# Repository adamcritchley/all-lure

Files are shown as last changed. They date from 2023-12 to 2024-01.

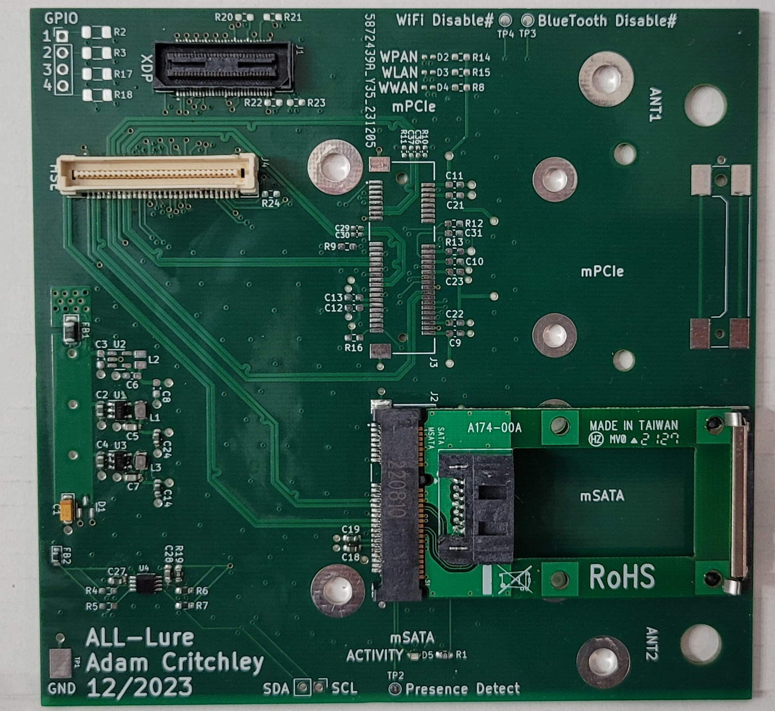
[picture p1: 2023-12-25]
images/top_with_sata.jpg

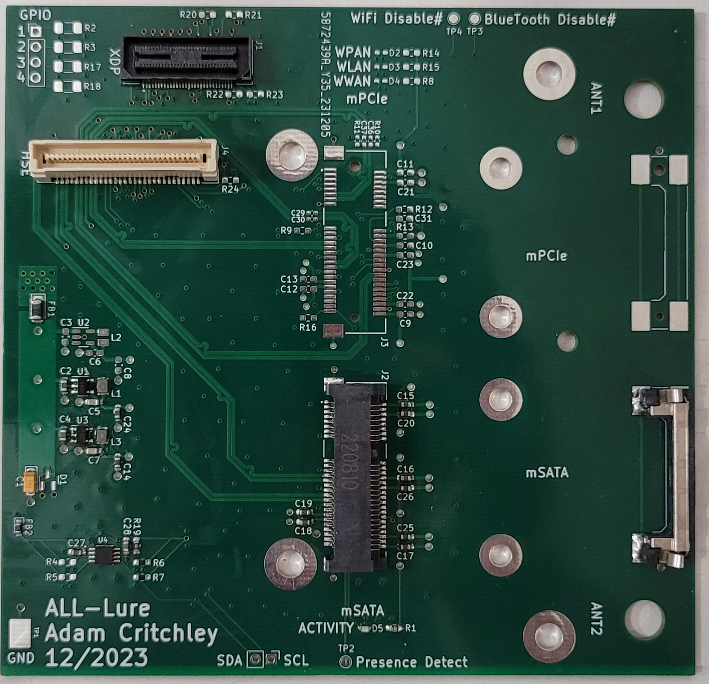
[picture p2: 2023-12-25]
images/top.jpg

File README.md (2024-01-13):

# Disclaimer
This board is still a prototype and is not functional. I was not able to fabricate it with working mSATA or mPCIe. I attempted to fabricate it with JLCPCB using both JLC041611-7628 and JLC041611-3313 impedance control. The presence detect for mSATA was pulled low however the MinnowBoard would not communicate with the mSATA card. I've decided not to continue troubleshooting this board and instead leave it as a learning experience in high-speed board design.

See [CM4-NAS-MiniPCIE](https://github.com/dumtux/CM4-NAS-MiniPCIE) as an example high-speed board designed for JLCPCB's JLC041611-7628 impedance control

# All-lure (GPIO, XDP, mPCIe, mSATA expansion for MinnowBoard)
All-lure is a custom "lure" expansion board for MinnowBoard Single Board Computers (SBC). The official hardware designs for MinnowBoard and the lures can be found at [MinnowBoards official GitHub](https://github.com/MinnowBoard-org/design-files). However, each board only exposes a single capability through the HSE (i.e. mSATA or mPCIe), instead I wanted a single board that combined as much of the lures capabilities into a single lure.

# Fabrication
This board does not work, please do not fabricate it. Currently it's designed for fabrication with JLCPCB using 1oz inner and outer copper weight and the standard JLC041611-7628 impedance control.

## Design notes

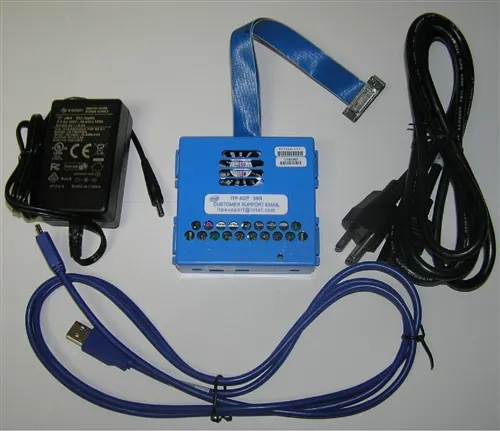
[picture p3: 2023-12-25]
images/ITPXDP3BREXT-2.png

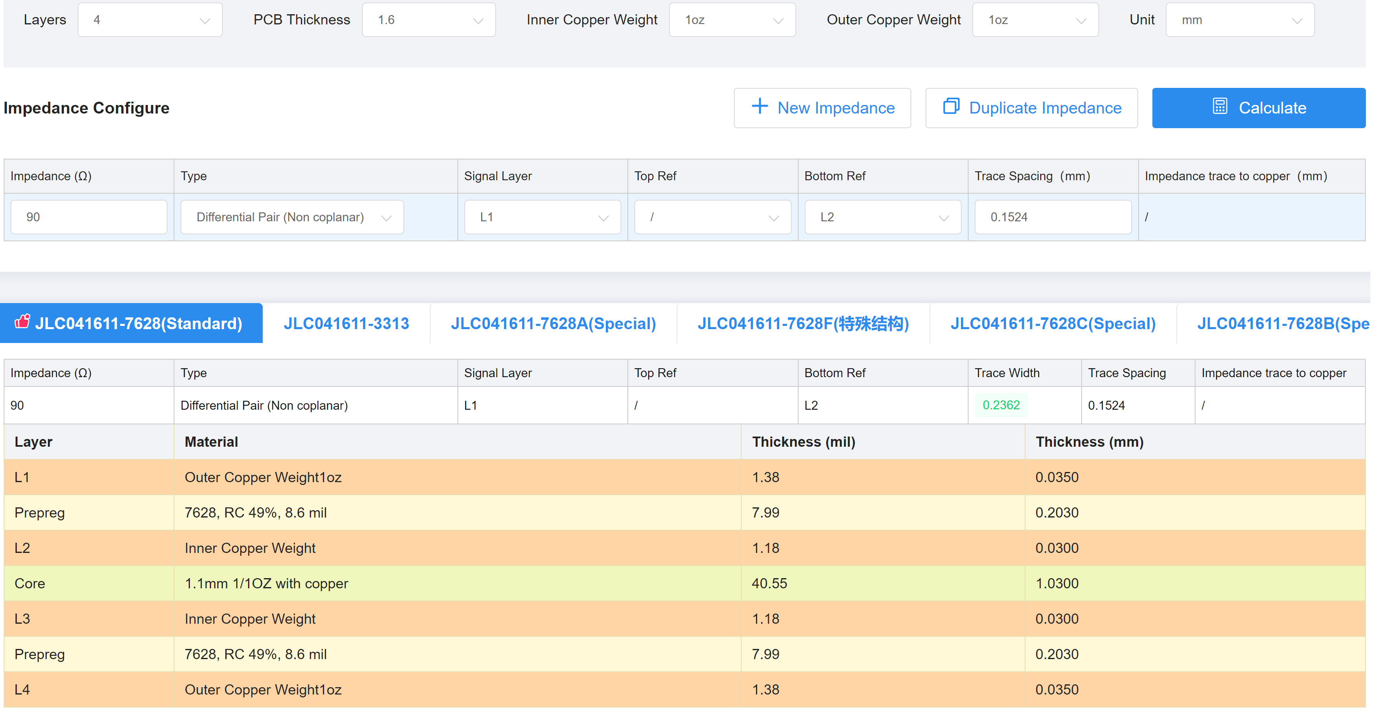
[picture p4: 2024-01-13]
images/usb_90R.png

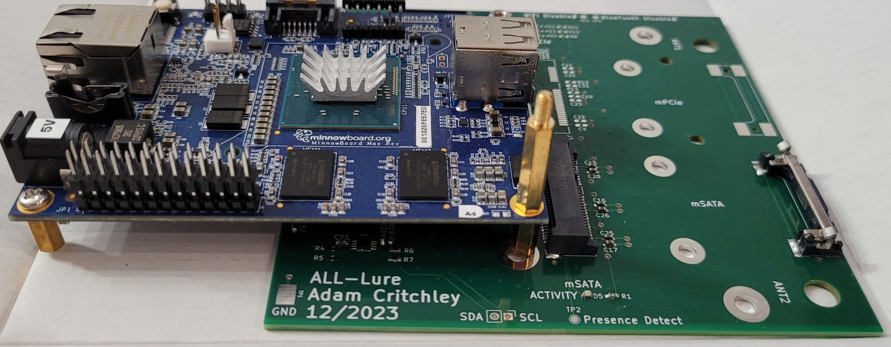
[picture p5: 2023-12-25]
images/side_mounted.jpg

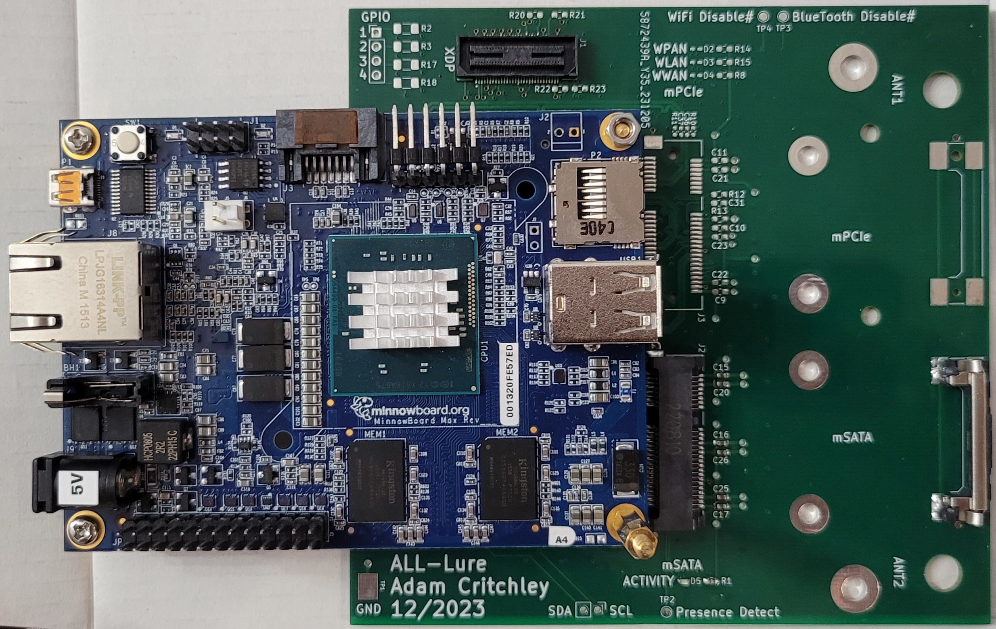
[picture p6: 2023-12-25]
images/top_mounted.jpg

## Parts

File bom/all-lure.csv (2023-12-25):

Index | Quantity | Part Number | Manufacturer Part Number | Description | Customer Reference | Available | Backorder | Unit Price | Extended Price USD
1 | 1 | 36-5095CT-ND | 5095 | SM TEST POINT ON T&R - COMPACT |  | 1 | 0 | 0.35000 | 0.35
2 | 1 | A99215CT-ND | 3-5177986-2 | CONN PLUG 60POS SMD GOLD |  | 1 | 0 | 4.06000 | 4.06
3 | 1 | SAM13103CT-ND | BSH-030-01-L-D-A-TR | CONN SOCKET 60POS SMD GOLD |  | 1 | 0 | 8.07000 | 8.07
4 | 2 | WM7125CT-ND | 0679105700 | CONN PCI EXP MIN FML 52POS 0.031 |  | 2 | 0 | 5.38000 | 10.76
5 | 2 | WM3733CT-ND | 0480995701 | LATCH ASSY FOR MINIPCI W/COVER |  | 2 | 0 | 1.70000 | 3.40
6 | 1 | 478-9042-1-ND | TPSA336K010R0700 | CAP TANT 33UF 10% 10V 1206 |  | 1 | 0 | 0.84000 | 0.84
7 | 4 | 160-1183-1-ND | LTST-C190GKT | LED GREEN CLEAR CHIP SMD |  | 4 | 0 | 0.23000 | 0.92
8 | 1 | 296-18509-1-ND | PCA9306DCTR | IC TRANSLATOR BIDIRECTIONAL SM8 |  | 1 | 0 | 0.65000 | 0.65
9 | 1 | 445-MMZ1608B601CTAH0CT-ND | MMZ1608B601CTAH0 | FERRITE BEAD 600 OHM 0603 1LN |  | 1 | 0 | 0.10000 | 0.10
10 | 3 | 587-5925-1-ND | MAKK2016T1R0M | FIXED IND 1UH 2.2A 75 MOHM SMD |  | 3 | 0 | 0.20000 | 0.60
11 | 1 | 587-LCMGA321616T221NGCT-ND | LCMGA321616T221NG | FERRITE BEAD 220 OHM 1206 1LN |  | 1 | 0 | 0.38000 | 0.38
12 | 3 | 1276-1274-1-ND | CL10A226MP8NUNE | CAP CER 22UF 10V X5R 0603 |  | 3 | 0 | 0.18000 | 0.54
13 | 2 | SC189ZSKCT-ND | SC189ZSKTRT | IC REG BUCK 3.3V 1.5A SOT23-5 |  | 2 | 0 | 1.20000 | 2.40
14 | 1 | 600-SC189HSKTRTCT-ND | SC189HSKTRT | IC REG BUCK 1.5V 1.5A SOT23-5 |  | 0 | 1 | 1.17000 | 1.17
15 | 1 | BAT54CLT3GOSCT-ND | BAT54CLT3G | DIODE ARR SCHOTT 30V 200MA SOT23 |  | 1 | 0 | 0.12000 | 0.12
16 | 3 | 1276-1019-1-ND | CL10B105KO8NNNC | CAP CER 1UF 16V X7R 0603 |  | 3 | 0 | 0.10000 | 0.30
17 | 18 | 1276-1005-1-ND | CL10B104KO8NNNC | CAP CER 0.1UF 16V X7R 0603 |  | 18 | 0 | 0.02600 | 0.47
18 | 4 | 4988-NMC0402X7R104K25TRPFCT-ND | NMC0402X7R104K25TRPF | CAP SMT04020.1F25VDC |  | 4 | 0 | 0.13000 | 0.52
19 | 3 | YAG5835CT-ND | SR0603FR-7T330RL | RES 330 OHM 1% 1/4W 0603 |  | 3 | 0 | 0.88000 | 2.64
20 | 3 | YAG5823CT-ND | SR0603FR-7T10KL | RES 10K OHM 1% 1/4W 0603 |  | 3 | 0 | 0.88000 | 2.64
21 | 2 | YAG5834CT-ND | SR0603FR-7T2K2L | RES 2.2K OHM 1% 1/4W 0603 |  | 2 | 0 | 0.88000 | 1.76
22 | 2 | YAG5821CT-ND | SR0603FR-7T100KL | RES 100K OHM 1% 1/4W 0603 |  | 2 | 0 | 0.88000 | 1.76
23 | 2 | 311-49.9LRCT-ND | RC0402FR-0749R9L | RES 49.9 OHM 1% 1/16W 0402 |  | 2 | 0 | 0.10000 | 0.20
24 | 1 | 13-RC0603FR-13200KLCT-ND | RC0603FR-13200KL | RES 200K OHM 1% 1/10W 0603 |  | 1 | 0 | 0.10000 | 0.10
25 | 3 | 13-RC0603JR-131KLCT-ND | RC0603JR-131KL | RES 1K OHM 5% 1/10W 0603 |  | 3 | 0 | 0.10000 | 0.30
26 | 4 | 311-10.0KFRCT-ND | RC1206FR-0710KL | RES 10K OHM 1% 1/4W 1206 |  | 4 | 0 | 0.10000 | 0.40
27 | 3 | 1276-1038-1-ND | CL10A106KQ8NNNC | CAP CER 10UF 6.3V X5R 0603 |  | 3 | 0 | 0.13000 | 0.39
28 | 4 | 952-2310-ND | R30-1000802 | HEX STANDOFF M3X0.5 BRASS 8MM |  | 4 | 0 | 0.58000 | 2.32

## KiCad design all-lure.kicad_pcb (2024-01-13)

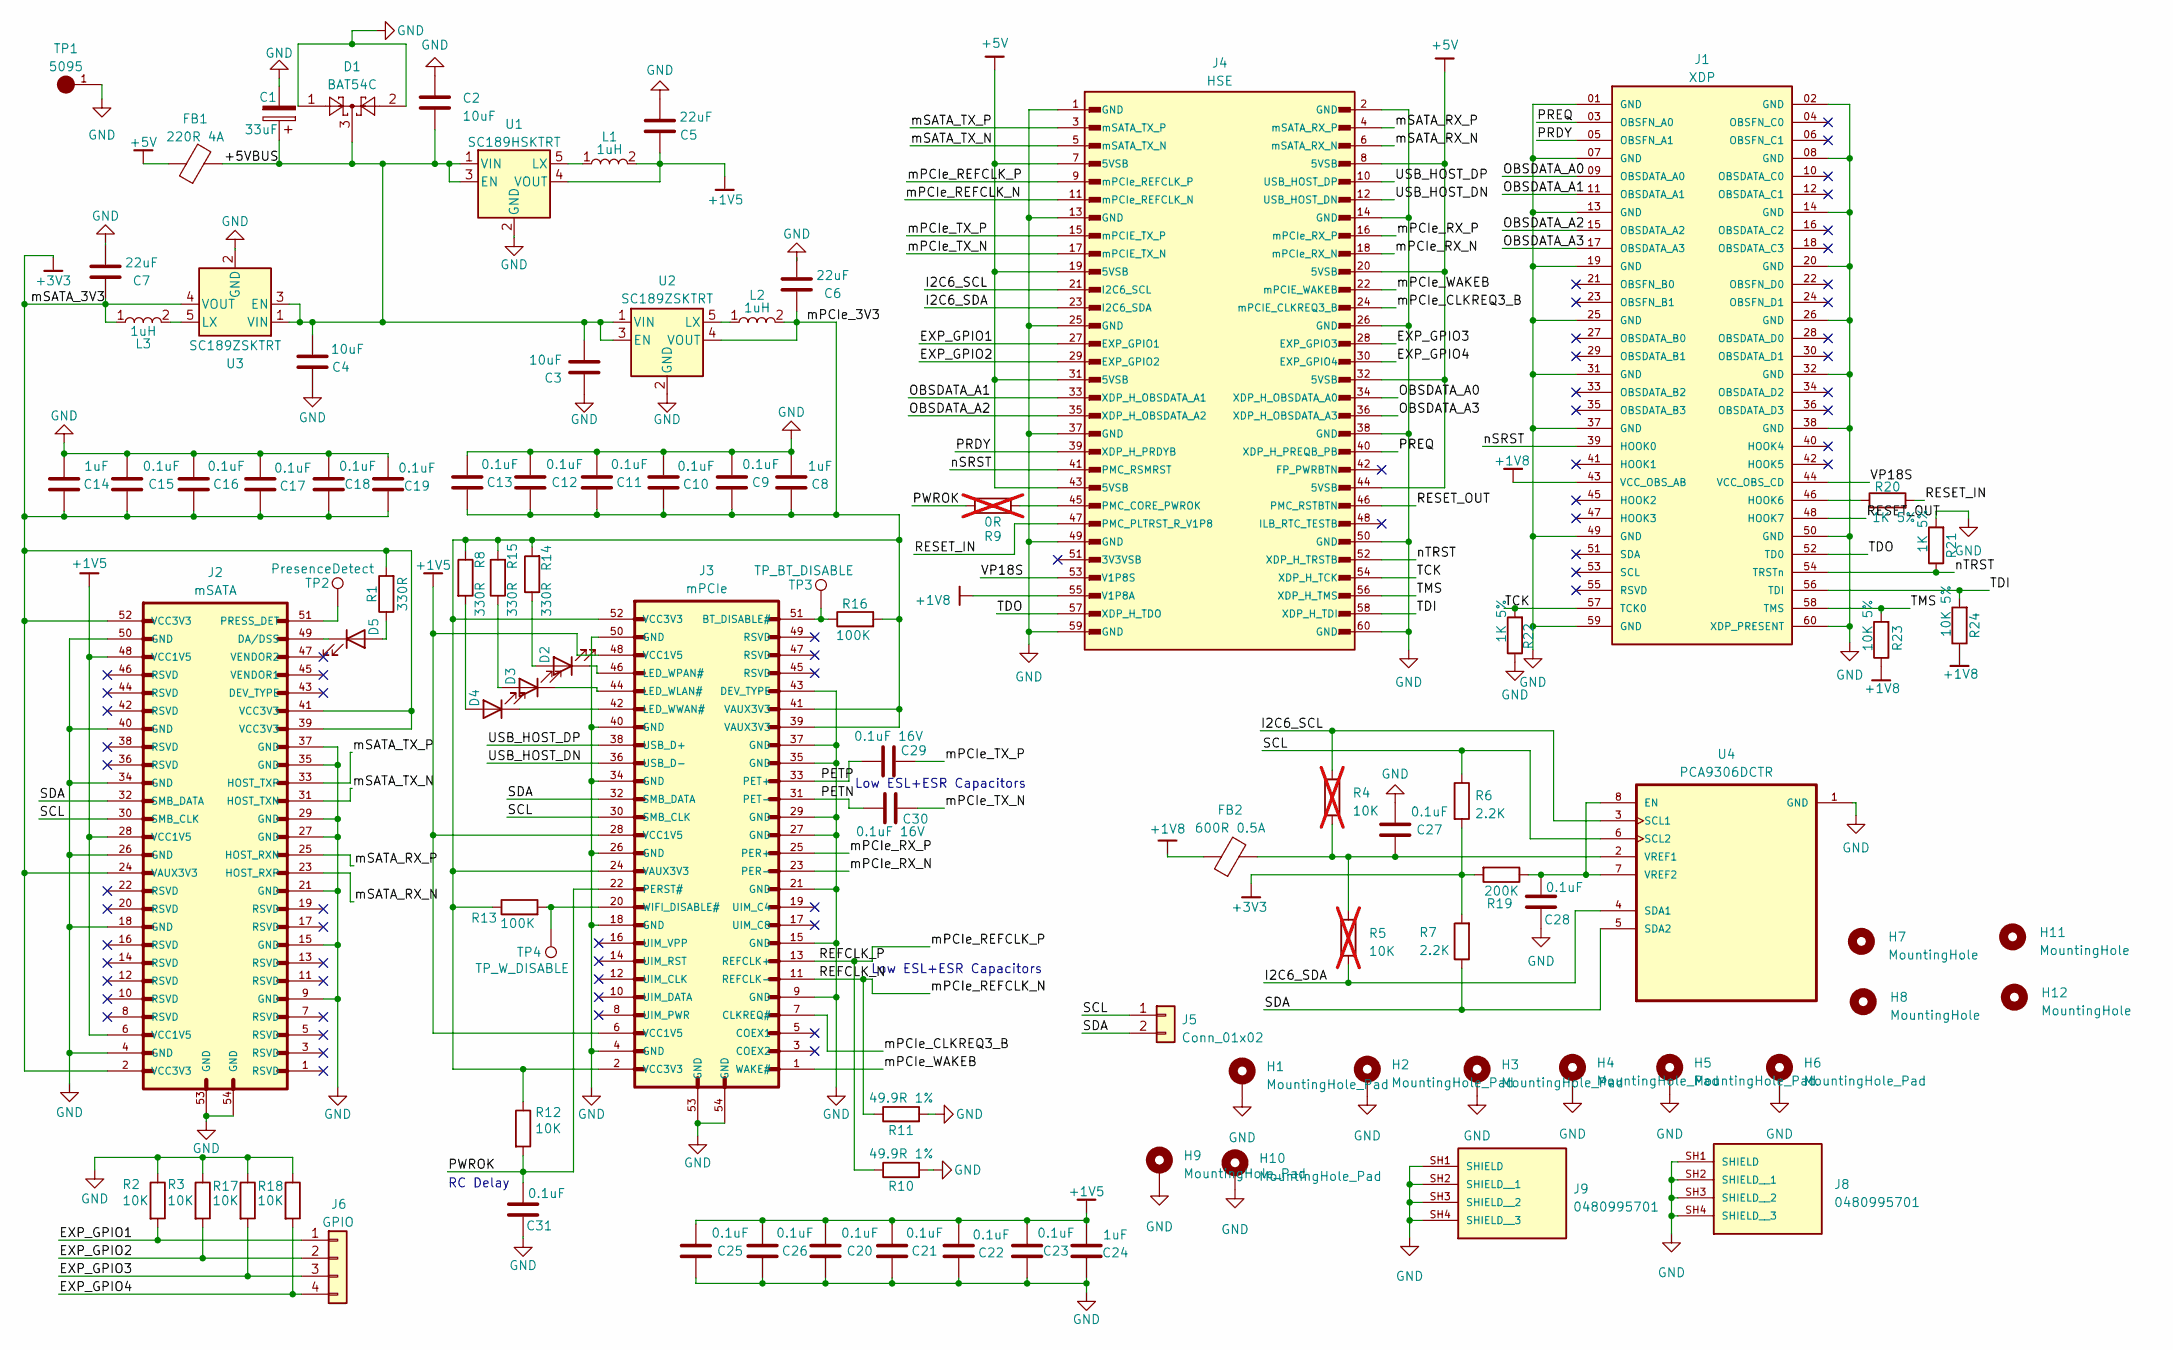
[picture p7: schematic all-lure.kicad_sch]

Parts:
C1: 33uF; CP_EIA-3216-18_Kemet-A_Pad1.58x1.35mm_HandSolder; MPN TPSA336K010R0700
C2, C3, C4: 10uF; C_0603_1608Metric_Pad1.08x0.95mm_HandSolder; MPN CL10A106KQ8NNNC
C5, C6, C7: 22uF; C_0603_1608Metric_Pad1.08x0.95mm_HandSolder; MPN CL10A226MP8NUNE
C8, C14, C24: 1uF; C_0603_1608Metric_Pad1.08x0.95mm_HandSolder; MPN CL10B105KO8NNNC
C9, C10, C11, C12, C13, C15, C16, C17, C18, C19, C20, C21, C22, C23, C25, C26, C27, C28, C31: 0.1uF; C_0603_1608Metric_Pad1.08x0.95mm_HandSolder; MPN CL10B104KO8NNNC
C29, C30: 0.1uF 16V; C_0402_1005Metric_Pad0.74x0.62mm_HandSolder; MPN NMC0402X7R104K25TRPF
D1: BAT54C; SOT-23; MPN BAT54CLT3G
D2, D3, D4, D5: LED; LTST-S270TGKT-HandSolder; MPN LTST-C190GKT
FB1: 220R 4A; D_1206_3216Metric_Pad1.42x1.75mm_HandSolder; MPN LCMGA321616T221NG
FB2: 600R 0.5A; D_0603_1608Metric_Pad1.05x0.95mm_HandSolder; MPN MMZ1608B601CTAH0
H1, H2, H9, H10: MountingHole_Pad; MountingHole_4.3mm_M4_Pad
H3, H4, H5, H6: MountingHole_Pad; MountingHole_3.5mm_Pad
H7, H8: MountingHole; MountingHole_6.4mm_M6_DIN965
H11, H12: MountingHole; MountingHole_3.2mm_M3_DIN965
J1: XDP; SAMTEC_BSH-030-01-X-D; PARTREV D
J2: mSATA; MOLEX_67910-5700; MPN 67910-5700
J3: mPCIe; MOLEX_67910-5700; MPN 67910-5700
J4: HSE; TE_3-5177986-2; PARTREV 9-06
J5: Conn_01x02; PinHeader_1x02_P2.54mm_Vertical
J6: GPIO; PinHeader_1x04_P2.54mm_Vertical
J8, J9: 0480995701; MOLEX_0480995701; PARTREV G
L1, L2, L3: 1uH; INDC2016X100N; MPN MAKK2016T1R0M
R1, R8, R14, R15: 330R; R_0603_1608Metric_Pad0.98x0.95mm_HandSolder; MPN SR0603FR-7T330RL
R2, R3, R17, R18: 10K; R_1206_3216Metric_Pad1.30x1.75mm_HandSolder; MPN RC1206FR-0710KL
R4, R5: 10K; R_0603_1608Metric_Pad0.98x0.95mm_HandSolder; not fitted
R6, R7: 2.2K; R_0603_1608Metric_Pad0.98x0.95mm_HandSolder; MPN SR0603FR-7T2K2L
R9: 0R; R_0603_1608Metric_Pad0.98x0.95mm_HandSolder; not fitted
R10, R11: 49.9R 1%; R_0402_1005Metric_Pad0.72x0.64mm_HandSolder; MPN RC0402FR-0749R9L
R12: 10K; R_0603_1608Metric_Pad0.98x0.95mm_HandSolder; MPN SR0603FR-7T10KL
R13, R16: 100K; R_0603_1608Metric_Pad0.98x0.95mm_HandSolder; MPN SR0603FR-7T100KL
R19: 200K; R_0603_1608Metric_Pad0.98x0.95mm_HandSolder; MPN RC0603FR-13200KL
R20, R21, R22: 1K 5%; R_0603_1608Metric_Pad0.98x0.95mm_HandSolder; MPN RC0603JR-131KL
R23, R24: 10K 5%; R_0603_1608Metric_Pad0.98x0.95mm_HandSolder; MPN RC1206FR-0710KL
TP1: 5095; KEYSTONE_5095; MPN 5095
TP2: PresenceDetect; TestPoint_Pad_D1.5mm
TP3: TP_BT_DISABLE; TestPoint_Pad_D1.5mm
TP4: TP_W_DISABLE; TestPoint_Pad_D1.5mm
U1: SC189HSKTRT; SOT-23-5; MPN SC189HSKTRT
U2, U3: SC189ZSKTRT; SOT-23-5; MPN SC189ZSKTRT
U4: PCA9306DCTR; SOP65P400X130-8N; MPN PCA9306DCTR; DigiKey_Part_Number 296-18509-2-ND

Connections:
+1V5: C5.1, C20.2, C21.2, C22.2, C23.2, C24.2, C25.2, C26.2, J2.6 (VCC1V5), J2.28 (VCC1V5), J2.48 (VCC1V5), J3.6 (VCC1V5), J3.28 (VCC1V5), J3.48 (VCC1V5), L1.2, U1.4 (VOUT)
+1V8: FB2.1, J1.43 (VCC_OBS_AB), J4.55 (V1P8A), R23.1, R24.1
+3V3: C7.1, C14.1, C15.1, C16.1, C17.1, C18.1, C19.1, J2.2 (VCC3V3), J2.24 (VAUX3V3), J2.39 (VCC3V3), J2.41 (VCC3V3), J2.52 (VCC3V3), L3.1, R1.2, R6.2, R7.2, R19.2, U3.4 (VOUT)
+5V: FB1.1, J4.7 (5VSB), J4.8 (5VSB), J4.19 (5VSB), J4.20 (5VSB), J4.31 (5VSB), J4.32 (5VSB), J4.43 (5VSB), J4.44 (5VSB)
/+5VBUS: C1.1, C2.1, C3.1, C4.1, D1.3, FB1.2, U1.1 (VIN), U1.3 (EN), U2.1 (VIN), U2.3 (EN), U3.1 (VIN), U3.3 (EN)
/EXP_GPIO1: J4.27 (EXP_GPIO1), J6.1, R2.2
/EXP_GPIO2: J4.29 (EXP_GPIO2), J6.2, R3.2
/EXP_GPIO3: J4.28 (EXP_GPIO3), J6.3, R17.2
/EXP_GPIO4: J4.30 (EXP_GPIO4), J6.4, R18.2
/I2C6_SCL: J4.21 (I2C6_SCL), R4.1, U4.3 (SCL1)
/I2C6_SDA: J4.23 (I2C6_SDA), R5.2, U4.4 (SDA1)
/OBSDATA_A0: J1.09 (OBSDATA_A0), J4.34 (XDP_H_OBSDATA_A0)
/OBSDATA_A1: J1.11 (OBSDATA_A1), J4.33 (XDP_H_OBSDATA_A1)
/OBSDATA_A2: J1.15 (OBSDATA_A2), J4.35 (XDP_H_OBSDATA_A2)
/OBSDATA_A3: J1.17 (OBSDATA_A3), J4.36 (XDP_H_OBSDATA_A3)
/PETN: C30.1, J3.31 (PET-)
/PETP: C29.1, J3.33 (PET+)
/PRDY: J1.05 (OBSFN_A1), J4.39 (XDP_H_PRDYB)
/PREQ: J1.03 (OBSFN_A0), J4.40 (XDP_H_PREQB_PB)
/PWROK: C31.2, J3.22 (PERST#), R9.2, R12.2
/REFCLK_N: J3.11 (REFCLK-), J4.11 (mPCIe_REFCLK_N), R11.1
/REFCLK_P: J3.13 (REFCLK+), J4.9 (mPCIe_REFCLK_P), R10.1
/RESET_IN: J4.47 (PMC_PLTRST_R_V1P8), R20.2
/RESET_OUT: J1.48 (HOOK7), J4.46 (PMC_RSTBTN)
/SCL: J2.30 (SMB_CLK), J3.30 (SMB_CLK), J5.1, R6.1, U4.6 (SCL2)
/SDA: J2.32 (SMB_DATA), J3.32 (SMB_DATA), J5.2, R7.1, U4.5 (SDA2)
/TCK: J1.57 (TCK0), J4.54 (XDP_H_TCK), R22.2
/TDI: J1.56 (TDI), J4.58 (XDP_H_TDI), R24.2
/TDO: J1.52 (TD0), J4.57 (XDP_H_TDO)
/TMS: J1.58 (TMS), J4.56 (XDP_H_TMS), R23.2
/USB_HOST_DN: J3.36 (USB_D-), J4.12 (USB_HOST_DN)
/USB_HOST_DP: J3.38 (USB_D+), J4.10 (USB_HOST_DP)
/VP18S: J1.44 (VCC_OBS_CD), J4.53 (V1P8S)
/mPCIe_3V3: C6.1, C8.1, C9.1, C10.1, C11.1, C12.1, C13.1, J3.2 (VCC3V3), J3.24 (VAUX3V3), J3.39 (VAUX3V3), J3.41 (VAUX3V3), J3.52 (VCC3V3), L2.2, R8.1, R12.1, R13.1, R14.2, R15.2, R16.2, U2.4 (VOUT)
/mPCIe_CLKREQ3_B: J3.7 (CLKREQ#), J4.24 (mPCIE_CLKREQ3_B)
/mPCIe_RX_N: J3.23 (PER-), J4.18 (mPCIe_RX_N)
/mPCIe_RX_P: J3.25 (PER+), J4.16 (mPCIe_RX_P)
/mPCIe_TX_N: C30.2, J4.17 (mPCIE_TX_N)
/mPCIe_TX_P: C29.2, J4.15 (mPCIE_TX_P)
/mPCIe_WAKEB: J3.1 (WAKE#), J4.22 (mPCIE_WAKEB)
/mSATA_RX_N: J2.23 (HOST_RXP), J4.6 (mSATA_RX_N)
/mSATA_RX_P: J2.25 (HOST_RXN), J4.4 (mSATA_RX_P)
/mSATA_TX_N: J2.31 (HOST_TXN), J4.5 (mSATA_TX_N)
/mSATA_TX_P: J2.33 (HOST_TXP), J4.3 (mSATA_TX_P)
/nSRST: J1.39 (HOOK0), J4.41 (PMC_RSMRST)
/nTRST: J1.54 (TRSTn), J4.52 (XDP_H_TRSTB), R21.1
GND: C1.2, C2.2, C3.2, C4.2, C5.2, C6.2, C7.2, C8.2, C9.2, C10.2, C11.2, C12.2, C13.2, C14.2, C15.2, C16.2, C17.2, C18.2, C19.2, C20.1, C21.1, C22.1, C23.1, C24.1, C25.1, C26.1, C27.2, C28.1, C31.1, D1.1, D1.2, H1.1, H2.1, H3.1, H4.1, H5.1, H6.1, H9.1, H10.1, J1.01 (GND), J1.02 (GND), J1.07 (GND), J1.08 (GND), J1.13 (GND), J1.14 (GND), J1.19 (GND), J1.20 (GND), J1.25 (GND), J1.26 (GND), J1.31 (GND), J1.32 (GND), J1.37 (GND), J1.38 (GND), J1.49 (GND), J1.50 (GND), J1.59 (GND), J1.60 (XDP_PRESENT), J2.4 (GND), J2.9 (GND), J2.15 (GND), J2.18 (GND), J2.21 (GND), J2.26 (GND), J2.27 (GND), J2.29 (GND), J2.34 (GND), J2.35 (GND), J2.37 (GND), J2.40 (GND), J2.50 (GND), J2.53 (GND), J2.54 (GND), J3.4 (GND), J3.9 (GND), J3.15 (GND), J3.18 (GND), J3.21 (GND), J3.26 (GND), J3.27 (GND), J3.29 (GND), J3.34 (GND), J3.35 (GND), J3.37 (GND), J3.40 (GND), J3.43 (DEV_TYPE), J3.50 (GND), J3.53 (GND), J3.54 (GND), J4.1 (GND), J4.2 (GND), J4.13 (GND), J4.14 (GND), J4.25 (GND), J4.26 (GND), J4.37 (GND), J4.38 (GND), J4.49 (GND), J4.50 (GND), J4.59 (GND), J4.60 (GND), J8.SH1 (SHIELD), J8.SH2 (SHIELD__1), J8.SH3 (SHIELD__2), J8.SH4 (SHIELD__3), J9.SH1 (SHIELD), J9.SH2 (SHIELD__1), J9.SH3 (SHIELD__2), J9.SH4 (SHIELD__3), R2.1, R3.1, R10.2, R11.2, R17.1, R18.1, R21.2, R22.1, TP1.1, U1.2 (GND), U2.2 (GND), U3.2 (GND), U4.1 (GND)
unnamed: D2.2 (A), R14.1
unnamed: D2.1 (K), J3.46 (LED_WPAN#)
unnamed: D3.2 (A), R15.1
unnamed: D3.1 (K), J3.44 (LED_WLAN#)
unnamed: D4.2 (A), R8.2
unnamed: D4.1 (K), J3.42 (LED_WWAN#)
unnamed: D5.2 (A), R1.1
unnamed: D5.1 (K), J2.49 (DA/DSS)
unnamed: J1.46 (HOOK6), R20.1
unnamed: J2.51 (PRESS_DET), TP2.1
unnamed: J3.51 (BT_DISABLE#), R16.1, TP3.1
unnamed: J3.20 (WIFI_DISABLE#), R13.2, TP4.1
unnamed: J4.45 (PMC_CORE_PWROK), R9.1
unnamed: L1.1, U1.5 (LX)
unnamed: L2.1, U2.5 (LX)
unnamed: L3.2, U3.5 (LX)
unnamed: C28.2, R19.1, U4.7 (VREF2), U4.8 (EN)
unnamed: C27.1, FB2.2, R4.2, R5.1, U4.2 (VREF1)

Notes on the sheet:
Low ESL+ESR Capacitors
RC Delay

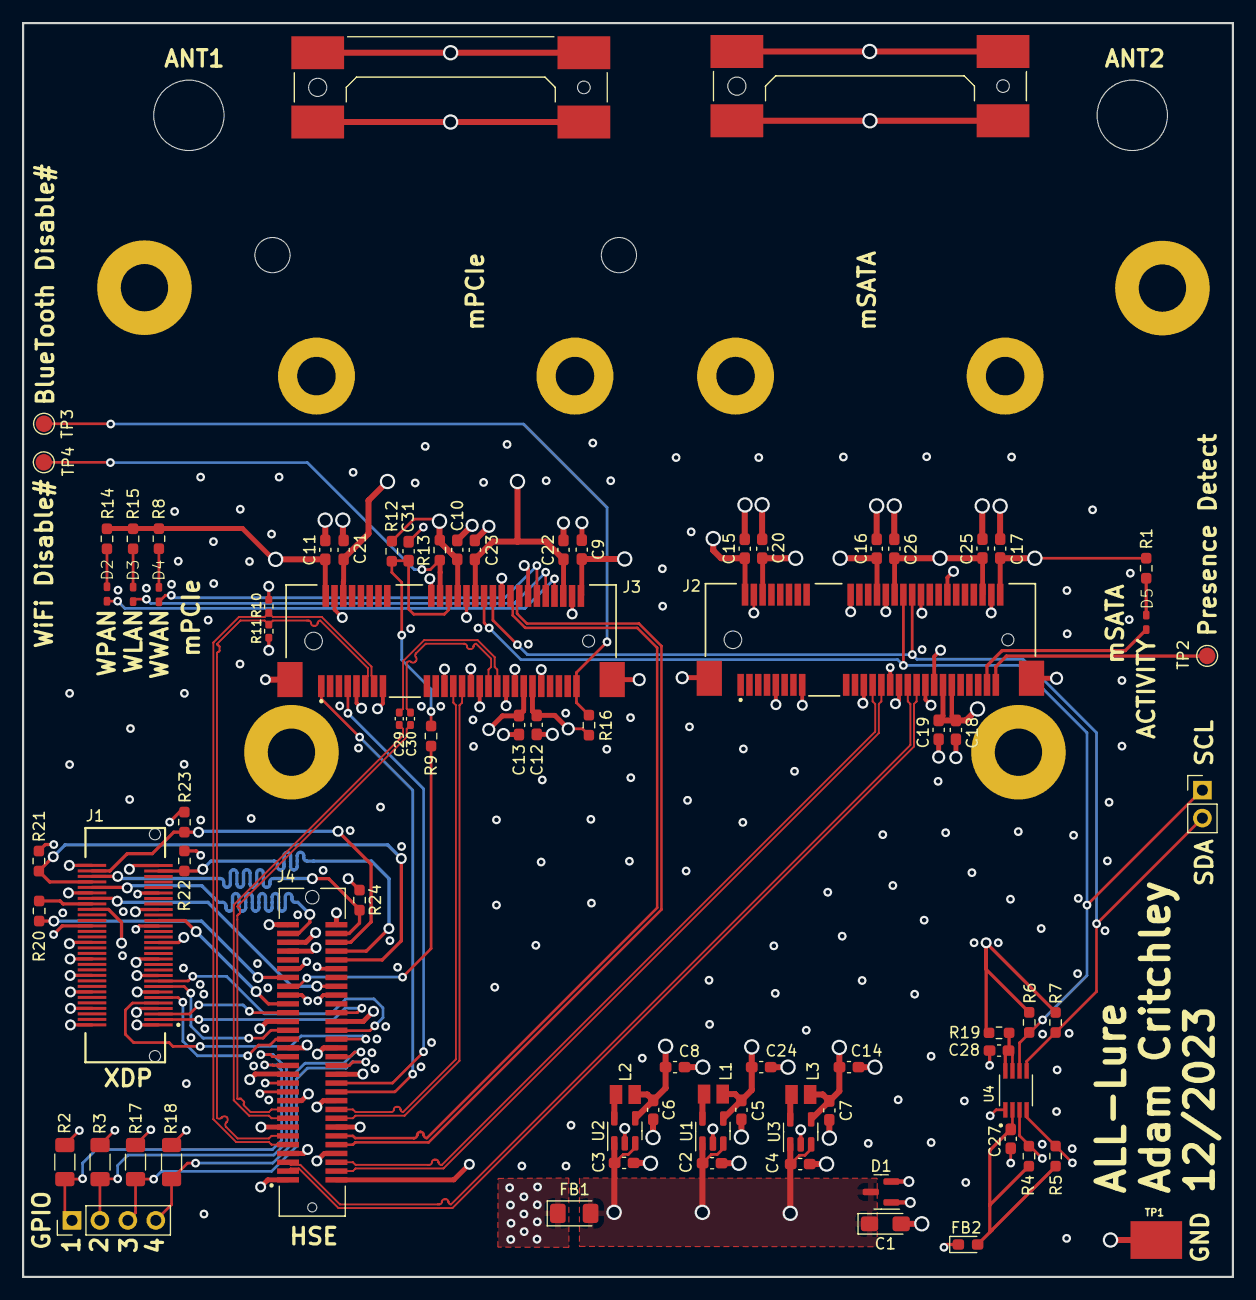
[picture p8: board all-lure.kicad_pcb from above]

Board: 4 copper layers, 110.0 x 114.0 mm, 93 parts (0 on the bottom side), 65 nets.

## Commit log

2023-12-28 fact(pcb): change trace width for 3313 fabrication. meander jtag traces. fix broken ground plane under pci ref clock.
    [all-lure.kicad_pcb]
2024-01-13 feat(pcb): update with latest attempt at mSATA and mPCIE
    [all-lure.kicad_pcb, all-lure.kicad_sch]
